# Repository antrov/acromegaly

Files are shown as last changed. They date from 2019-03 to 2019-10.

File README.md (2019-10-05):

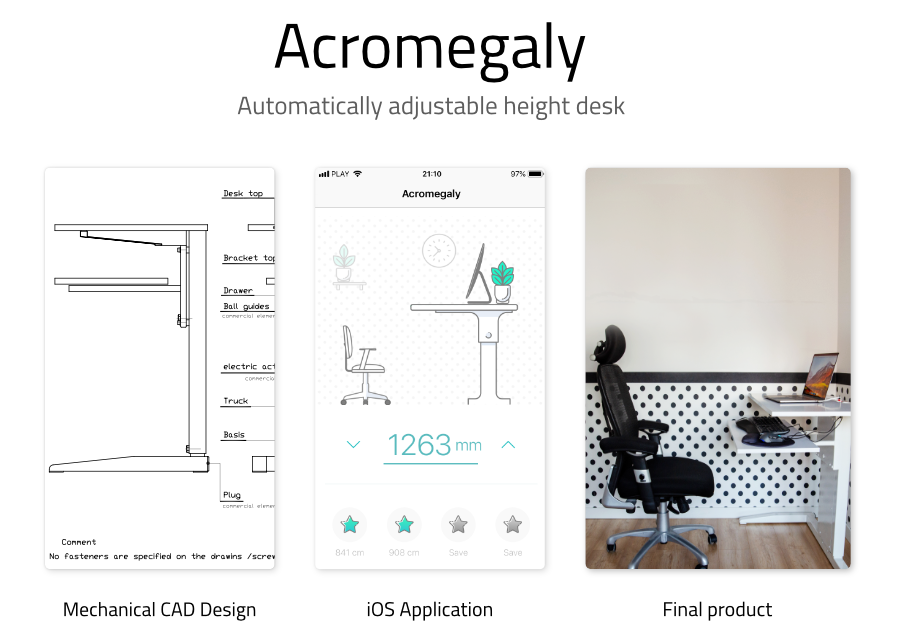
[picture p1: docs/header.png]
Header Image


Acromegaly is an open source project of the desk with automatically adjustable height. Position of the desk is controlled by Bluetooth Low Energy interface and dedicated iOS Application. 

Provided designs allows
* to build a mechanical frame of the desk, 
* to manufacture and program a controller and finally 
* to build a BLE client app. 

Total cost of components, manufacture and final polish is around 100$. 

Demo GIF

## CAD project

[GitHub repo](https://github.com/antrov/acromegaly/tree/master/CAD)
 
Full documentation of mechanical parts of the desk: frame, rails, driver mounting and desktop. Supplied in english and polish.

Designed and created by Msc Leszek Andrzejewski.

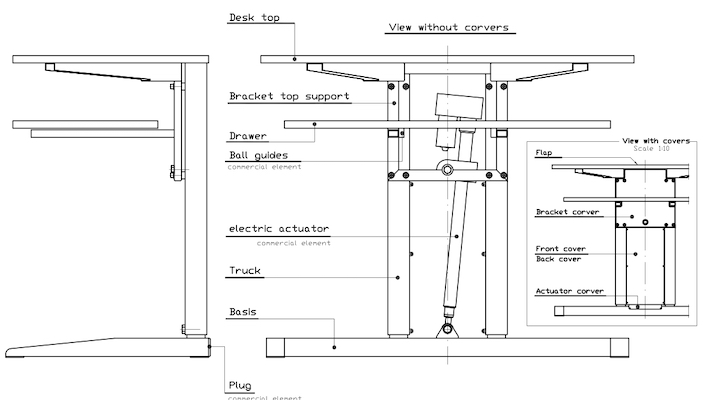
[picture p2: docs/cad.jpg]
CAD project


## PCB schematic and design

[GitHub repo](https://github.com/antrov/acromegaly/tree/master/PCB)

[Eagle](https://www.autodesk.com/products/eagle/overview) files used to design and manufacture the base PCB with a BLE controller and driver connectors. Besides, board includes an op-amp used to amplify current measurements for ADC, as well as a 8MB Flash memory. 

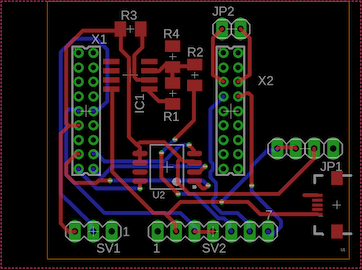
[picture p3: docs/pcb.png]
PCB Design
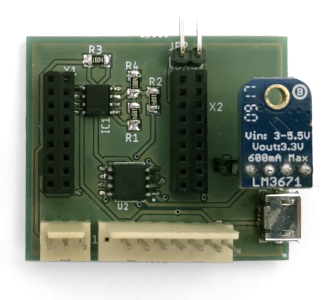
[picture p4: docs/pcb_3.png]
PCB real photo
 

## BLE controller (nRF51)

[GitHub repo](https://github.com/antrov/acromegaly-nrf51)

ANSI C code developed for the nRF51 MCU and based on its SDK. The brain of a desk controller, exposes interface for receiving commands from Bluetooth Low Energy and to broadcasts informations like: 
* current height, 
* target height, 
* movement state and direction, 
* current power 

Configured to compile with wide available and free toolchains.

## BLE client (iOS)

[GitHub repo](https://github.com/antrov/acromegaly-ios)

Swift iOS application used to present visually state of the desk and control it remotely.

* auto scanning and connecting to dedicated Acromegaly BLE device
* visual representation of current and requested desk height
* setting exact height of a desk
* swipe gesture to set bounding positions
* storing of the favourites positions

iOS Client App iOS Client App

## Contact
In case of new issues, concepts or just a will to say hello:

* antrof@gmail.com
* https://www.linkedin.com/in/handr/

## License 

Copyright 2019 Hubert Andrzejewski

This code is distributed under the terms and conditions of the MIT license.

```
Permission is hereby granted, free of charge, to any person obtaining a copy of
this software and associated documentation files (the "Software"), to deal in
the Software without restriction, including without limitation the rights to
use, copy, modify, merge, publish, distribute, sublicense, and/or sell copies of
the Software, and to permit persons to whom the Software is furnished to do so,
subject to the following conditions:

The above copyright notice and this permission notice shall be included in all
copies or substantial portions of the Software.

THE SOFTWARE IS PROVIDED "AS IS", WITHOUT WARRANTY OF ANY KIND, EXPRESS OR
IMPLIED, INCLUDING BUT NOT LIMITED TO THE WARRANTIES OF MERCHANTABILITY, FITNESS
FOR A PARTICULAR PURPOSE AND NONINFRINGEMENT. IN NO EVENT SHALL THE AUTHORS OR
COPYRIGHT HOLDERS BE LIABLE FOR ANY CLAIM, DAMAGES OR OTHER LIABILITY, WHETHER
IN AN ACTION OF CONTRACT, TORT OR OTHERWISE, ARISING FROM, OUT OF OR IN
CONNECTION WITH THE SOFTWARE OR THE USE OR OTHER DEALINGS IN THE SOFTWARE.
```

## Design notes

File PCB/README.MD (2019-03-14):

# Acromegaly PCB

[Eagle](https://www.autodesk.com/products/eagle/overview) files used to design and manufacture the base PCB with a BLE controller and driver connectors. Besides, board includes an op-amp used to amplify current measurements for ADC, as well as a 8MB Flash memory. 

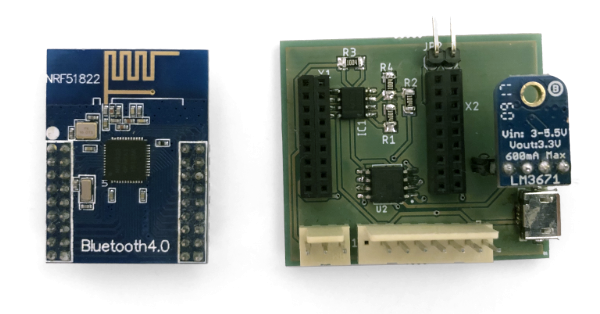
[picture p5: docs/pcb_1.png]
PCB


## Required parts:
* 2mm raster 4x9 connectors
* 2.74mm raster goldpin connectors
* M45PE80 - 8MB FLASH Memory
* LM358 - op-amp for current measurement
* double BTS 7960 as H-Bridge driver - [sample](http://www.alselectro.com/motor-driver-hbridge-43amps-bts7960.html)
* LM3671 3.3V Buck Converter Breakout - 3.3V - step-down power supply from 5V to 3.3V - [sample](https://www.adafruit.com/product/2745)
* nRF51 Core Board - 2mm raster pins - [sample](https://www.waveshare.com/core51822.htm)
* 4x 1MΩ -  SMD 1206 Resitors
* LM393 with slot detector - [sample](https://www.electrokit.com/produkt/modul-med-optisk-lasgaffel/)
* Mask for slot detector - [PDF](https://github.com/antrov/acromegaly/tree/master/PCB/gap_mask.pdf)

## Flashing

During development on DK board, flashing is done by integrated JLink (SEGGER) programmer. In order to flash Acromegaly PCB it is necessary to connect DK VVC/GND instead of LM3671 and SWDIO/SWCLK to dedicated PCB connectors accoriding to [following rules](https://electronut.in/nrf51-dk-external-programming/)

## Slot detector

[Mask PDF](https://github.com/antrov/acromegaly/tree/master/PCB/gap_mask.pdf)

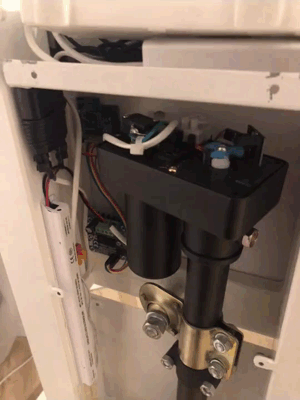
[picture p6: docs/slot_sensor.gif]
Slot senor in action


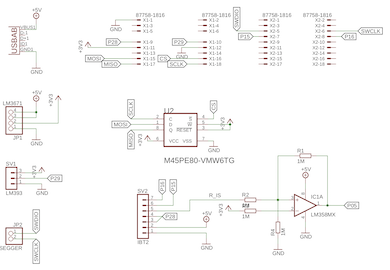
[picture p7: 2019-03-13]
docs/schematic.png

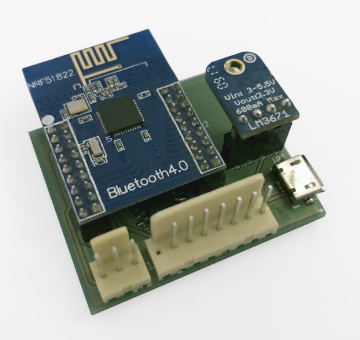
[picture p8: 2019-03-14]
docs/pcb_2.png

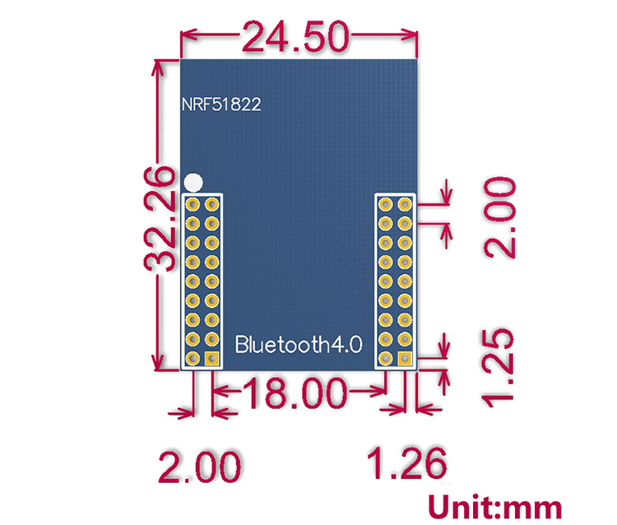
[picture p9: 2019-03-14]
PCB/Datasheets/Core51822-size.jpg

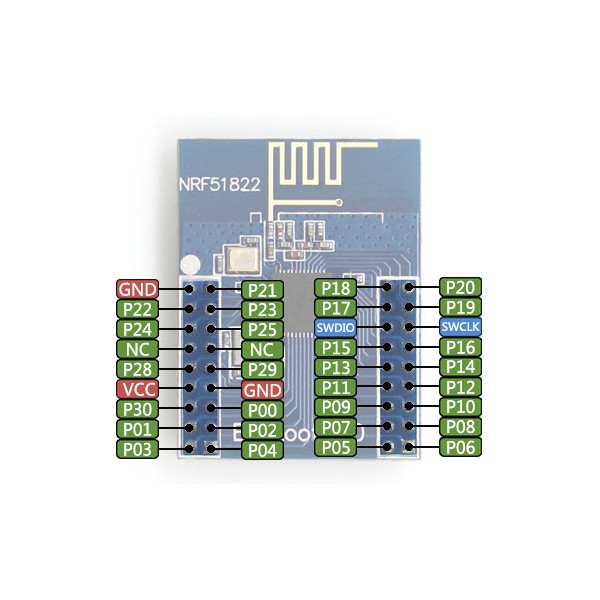
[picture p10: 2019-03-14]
PCB/Datasheets/core51822-board.jpg

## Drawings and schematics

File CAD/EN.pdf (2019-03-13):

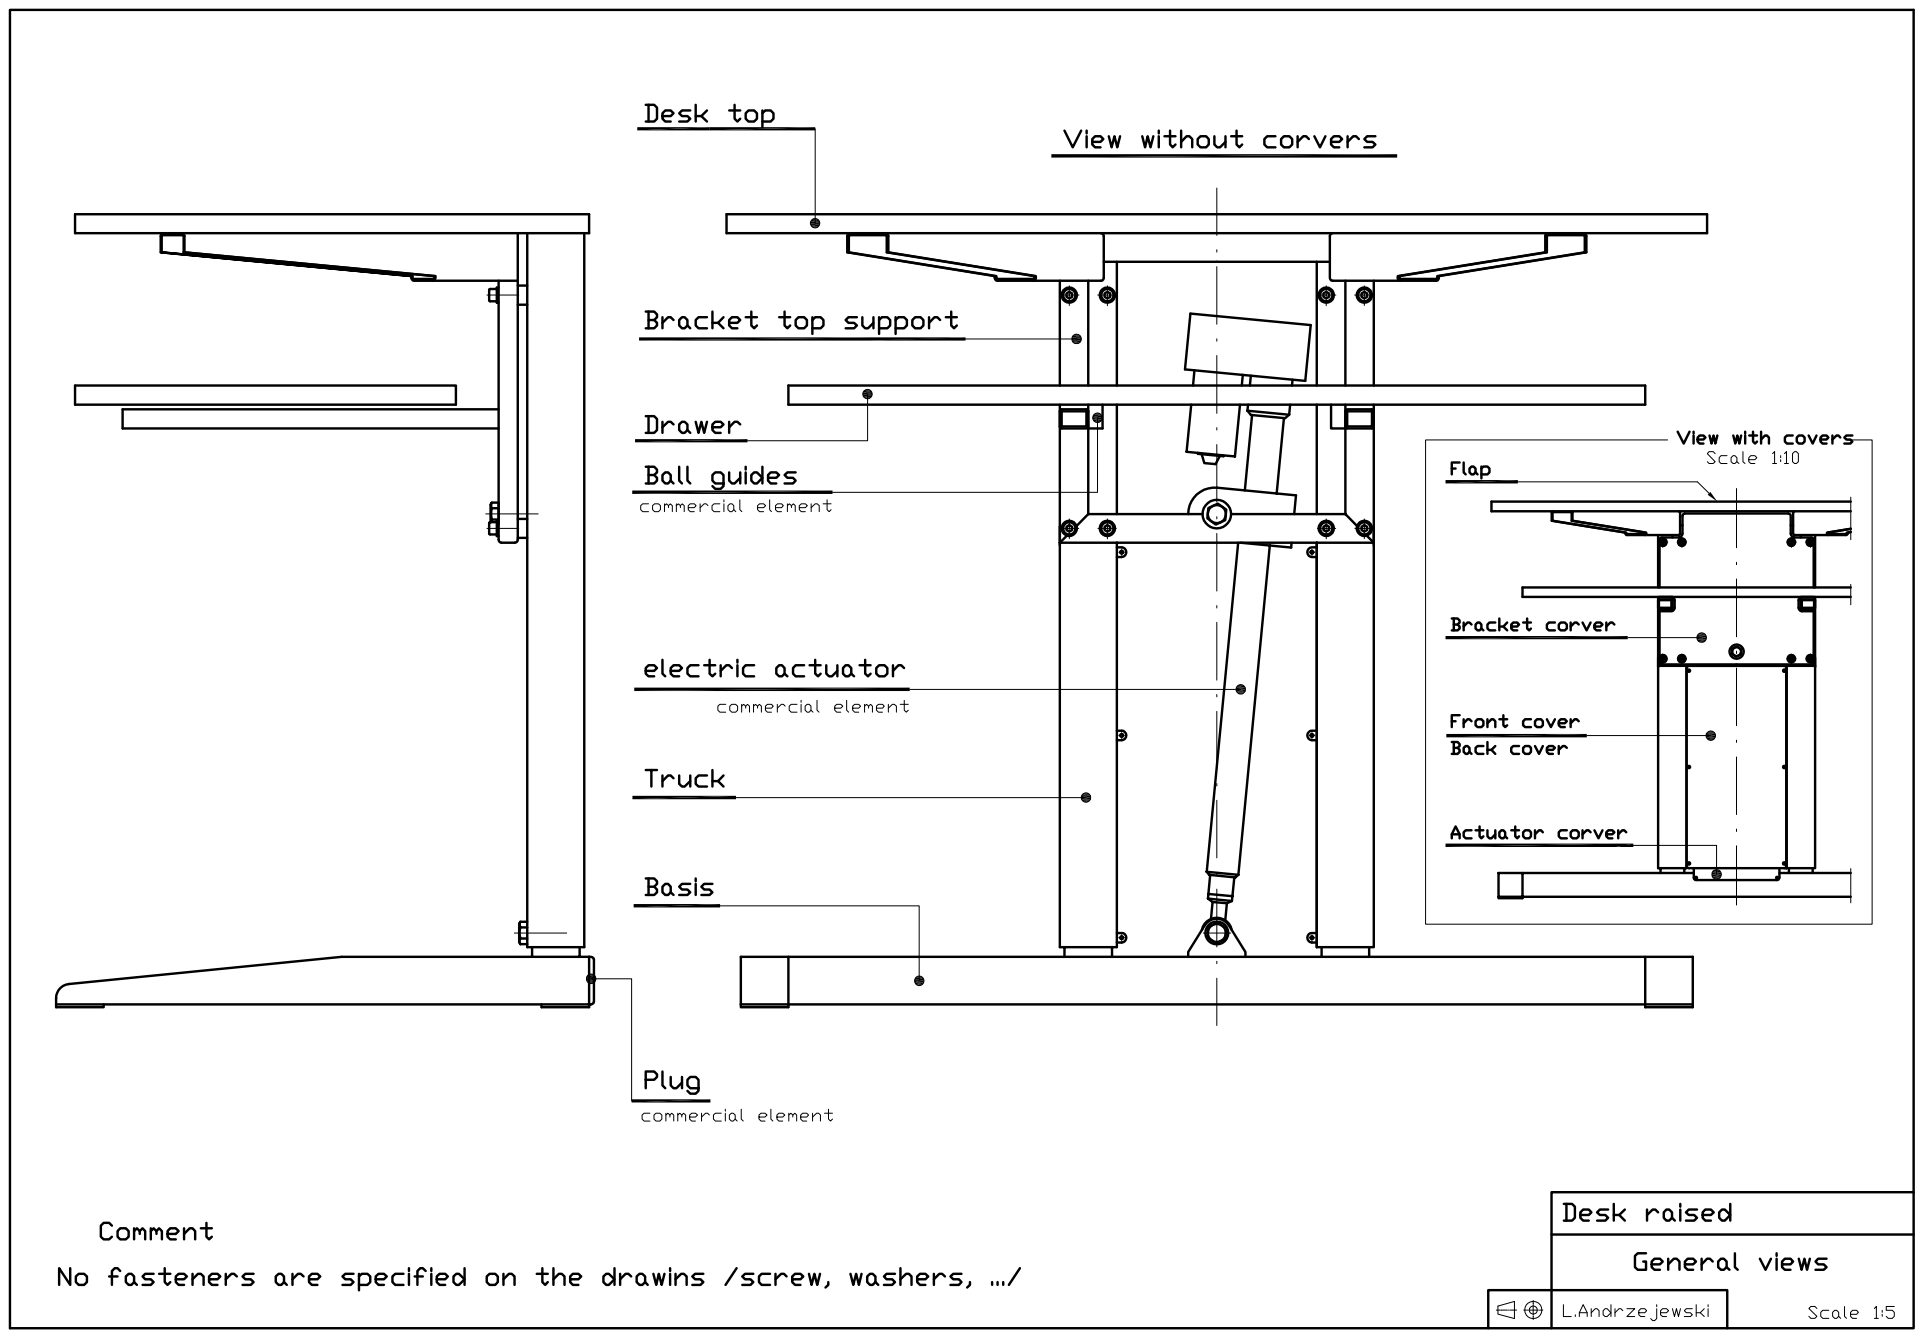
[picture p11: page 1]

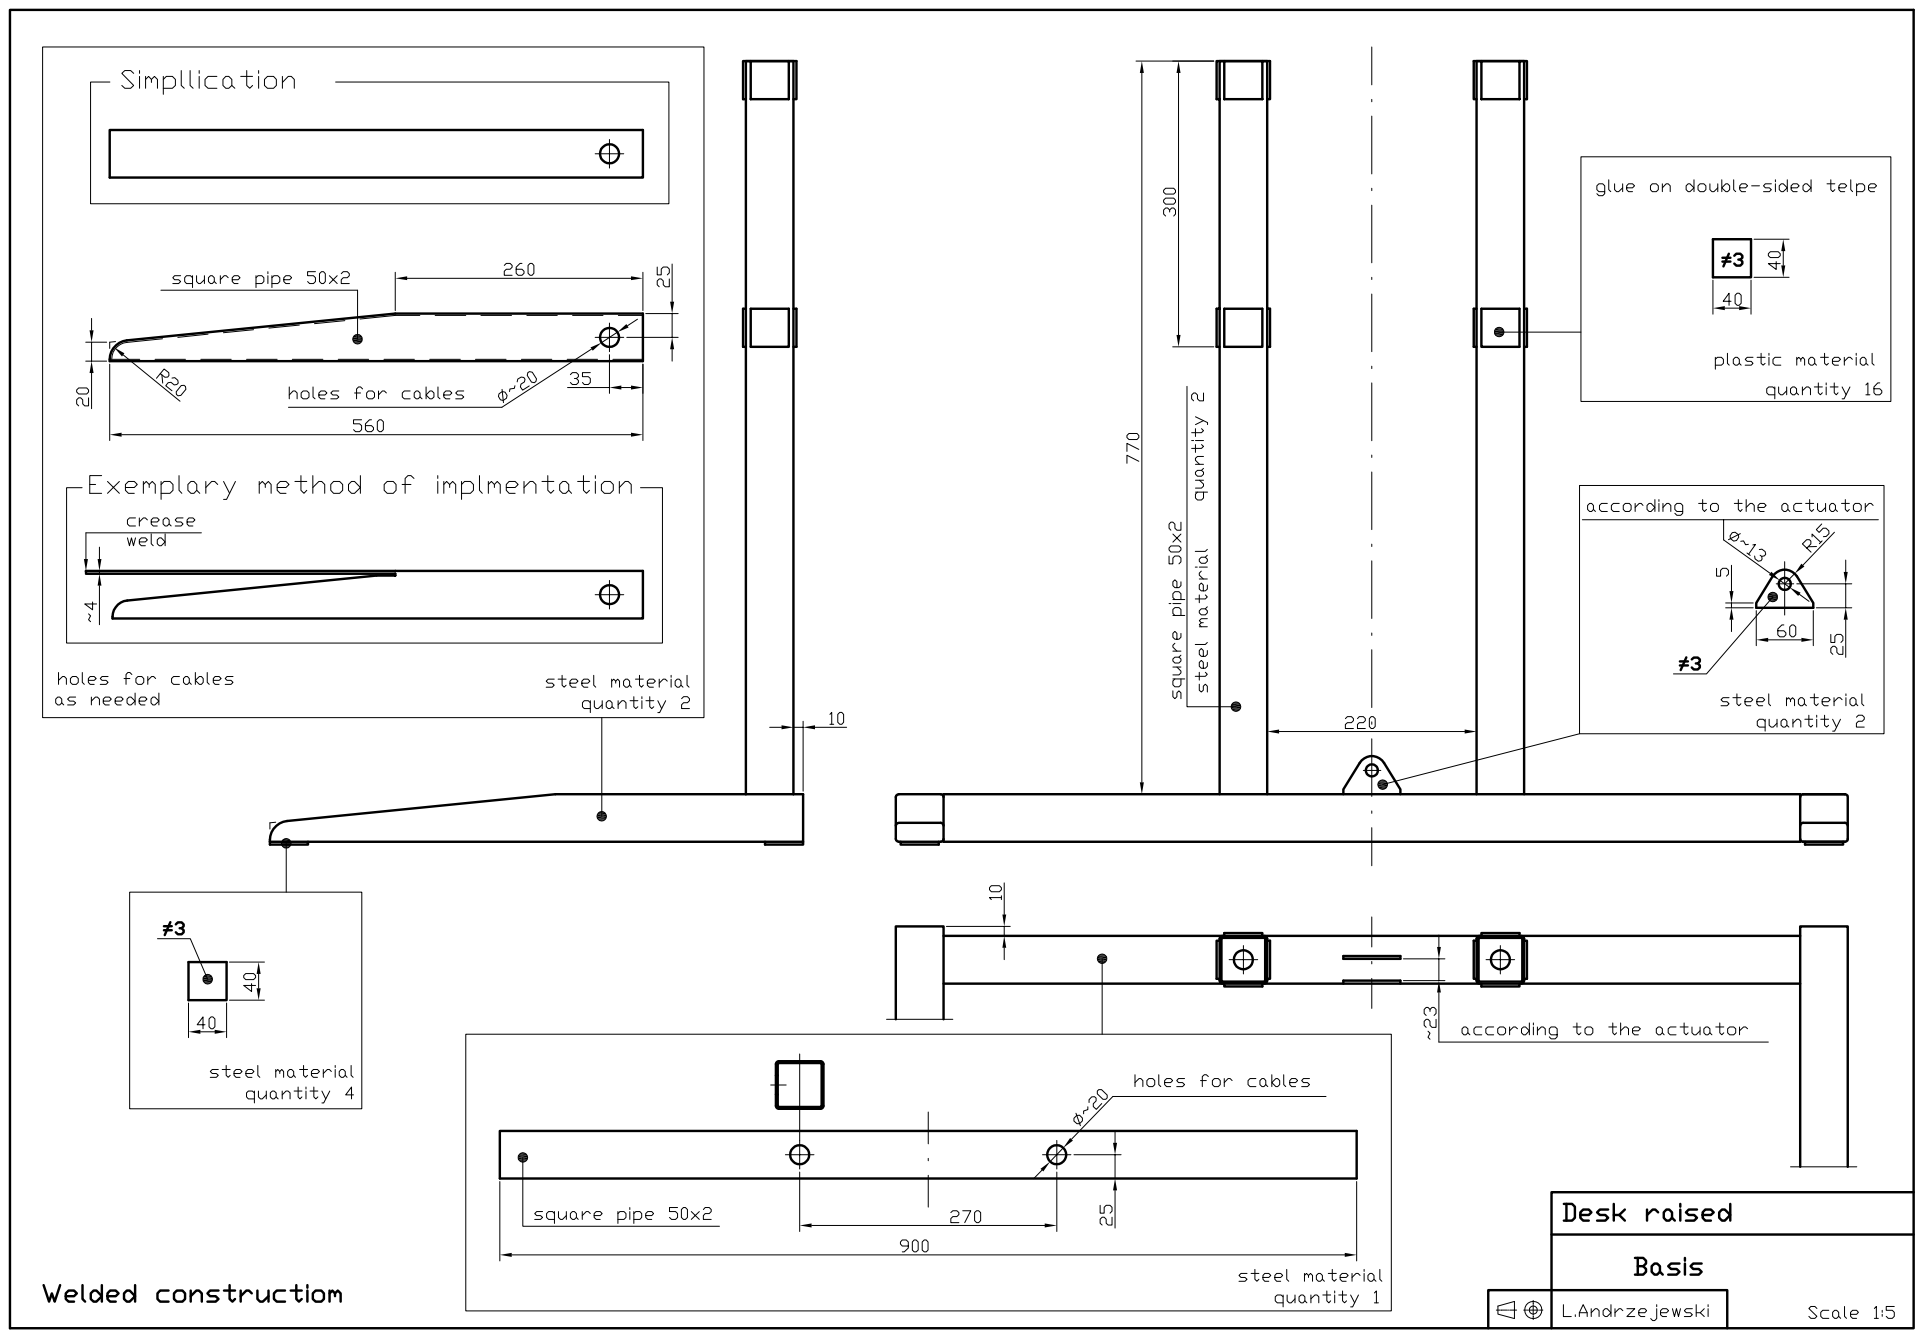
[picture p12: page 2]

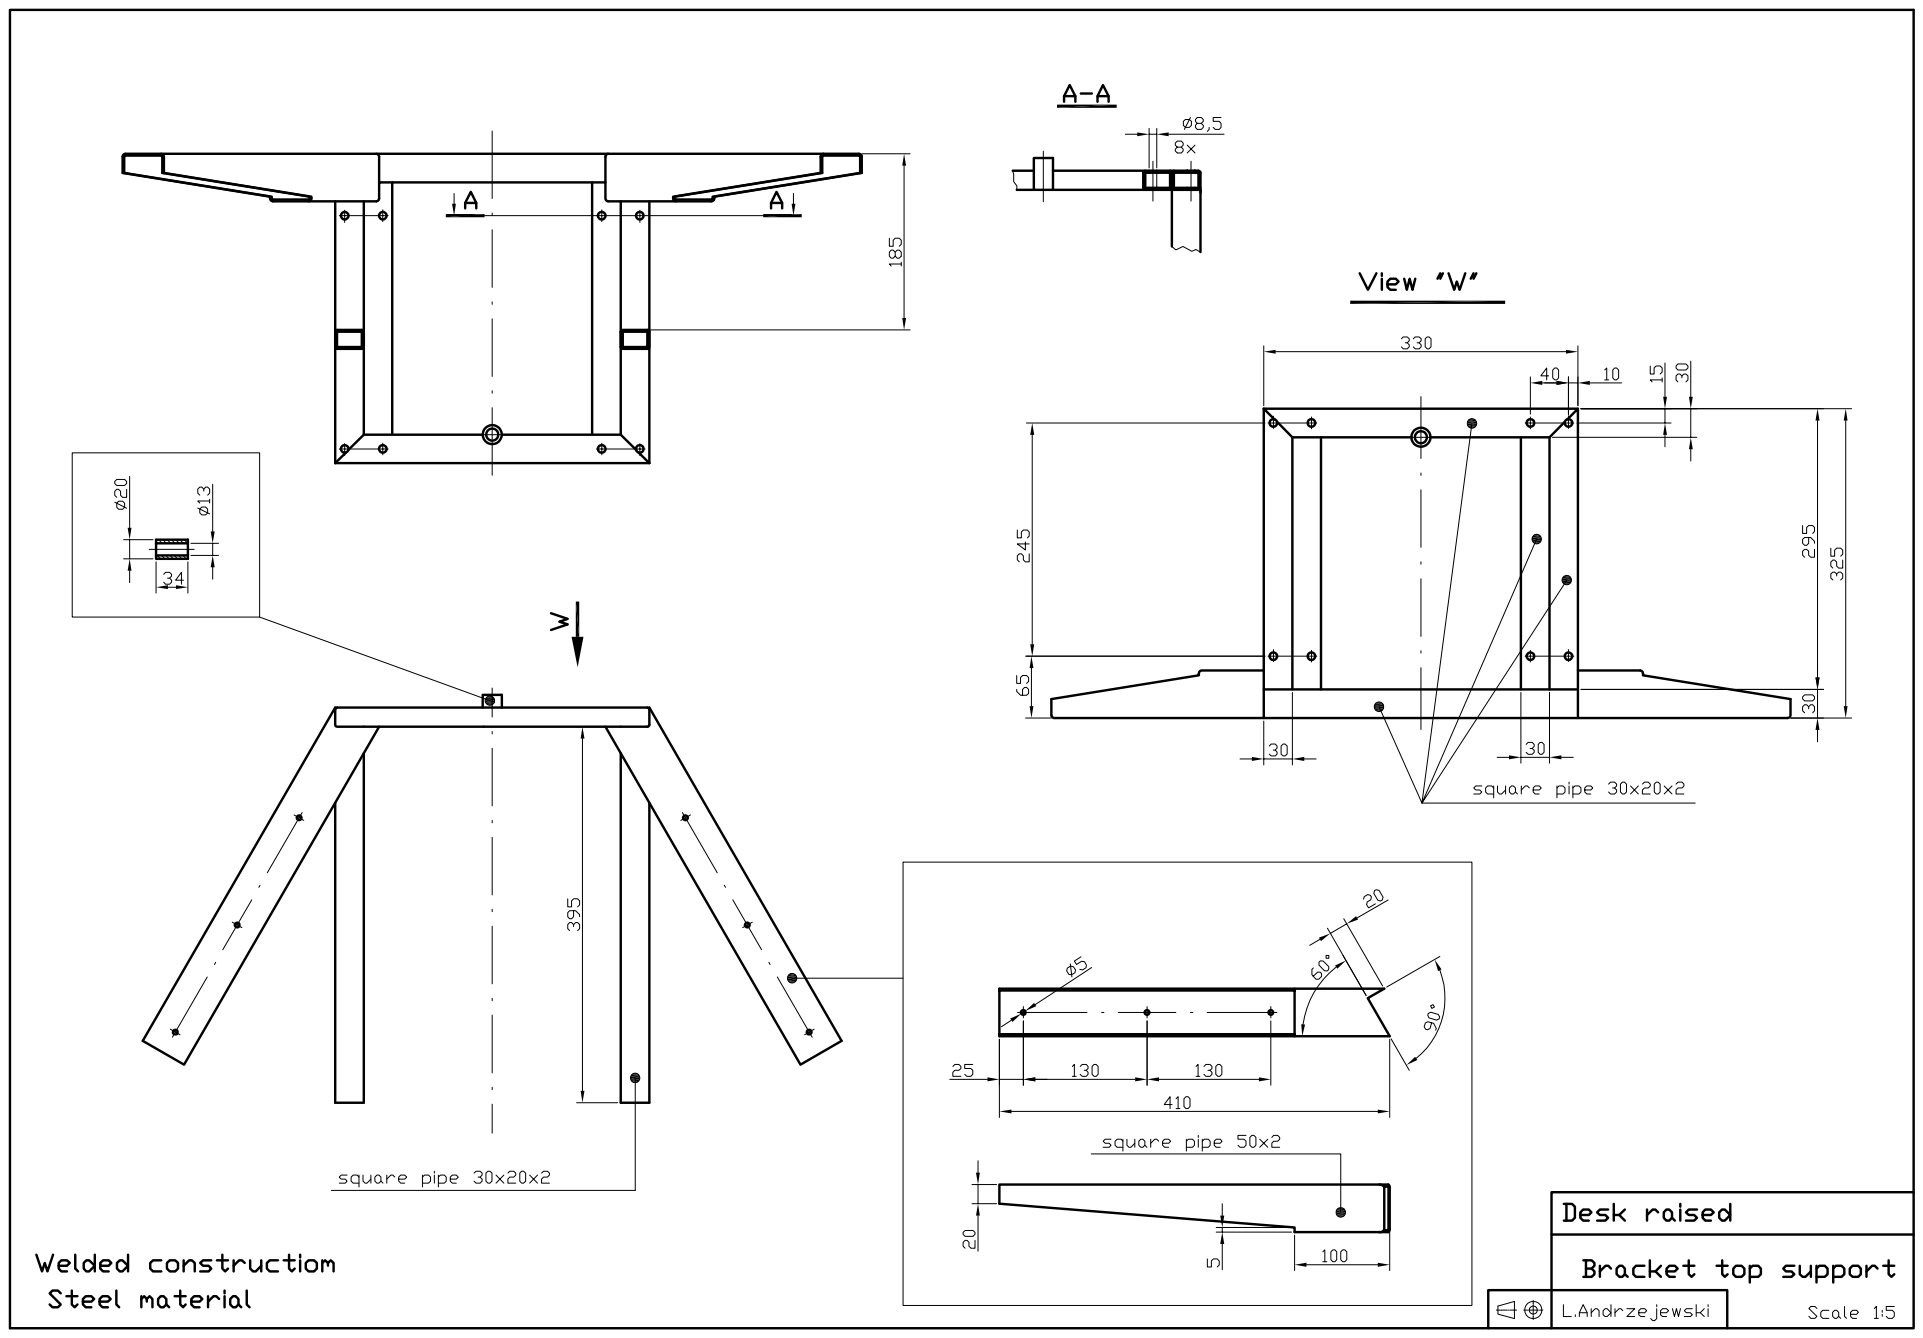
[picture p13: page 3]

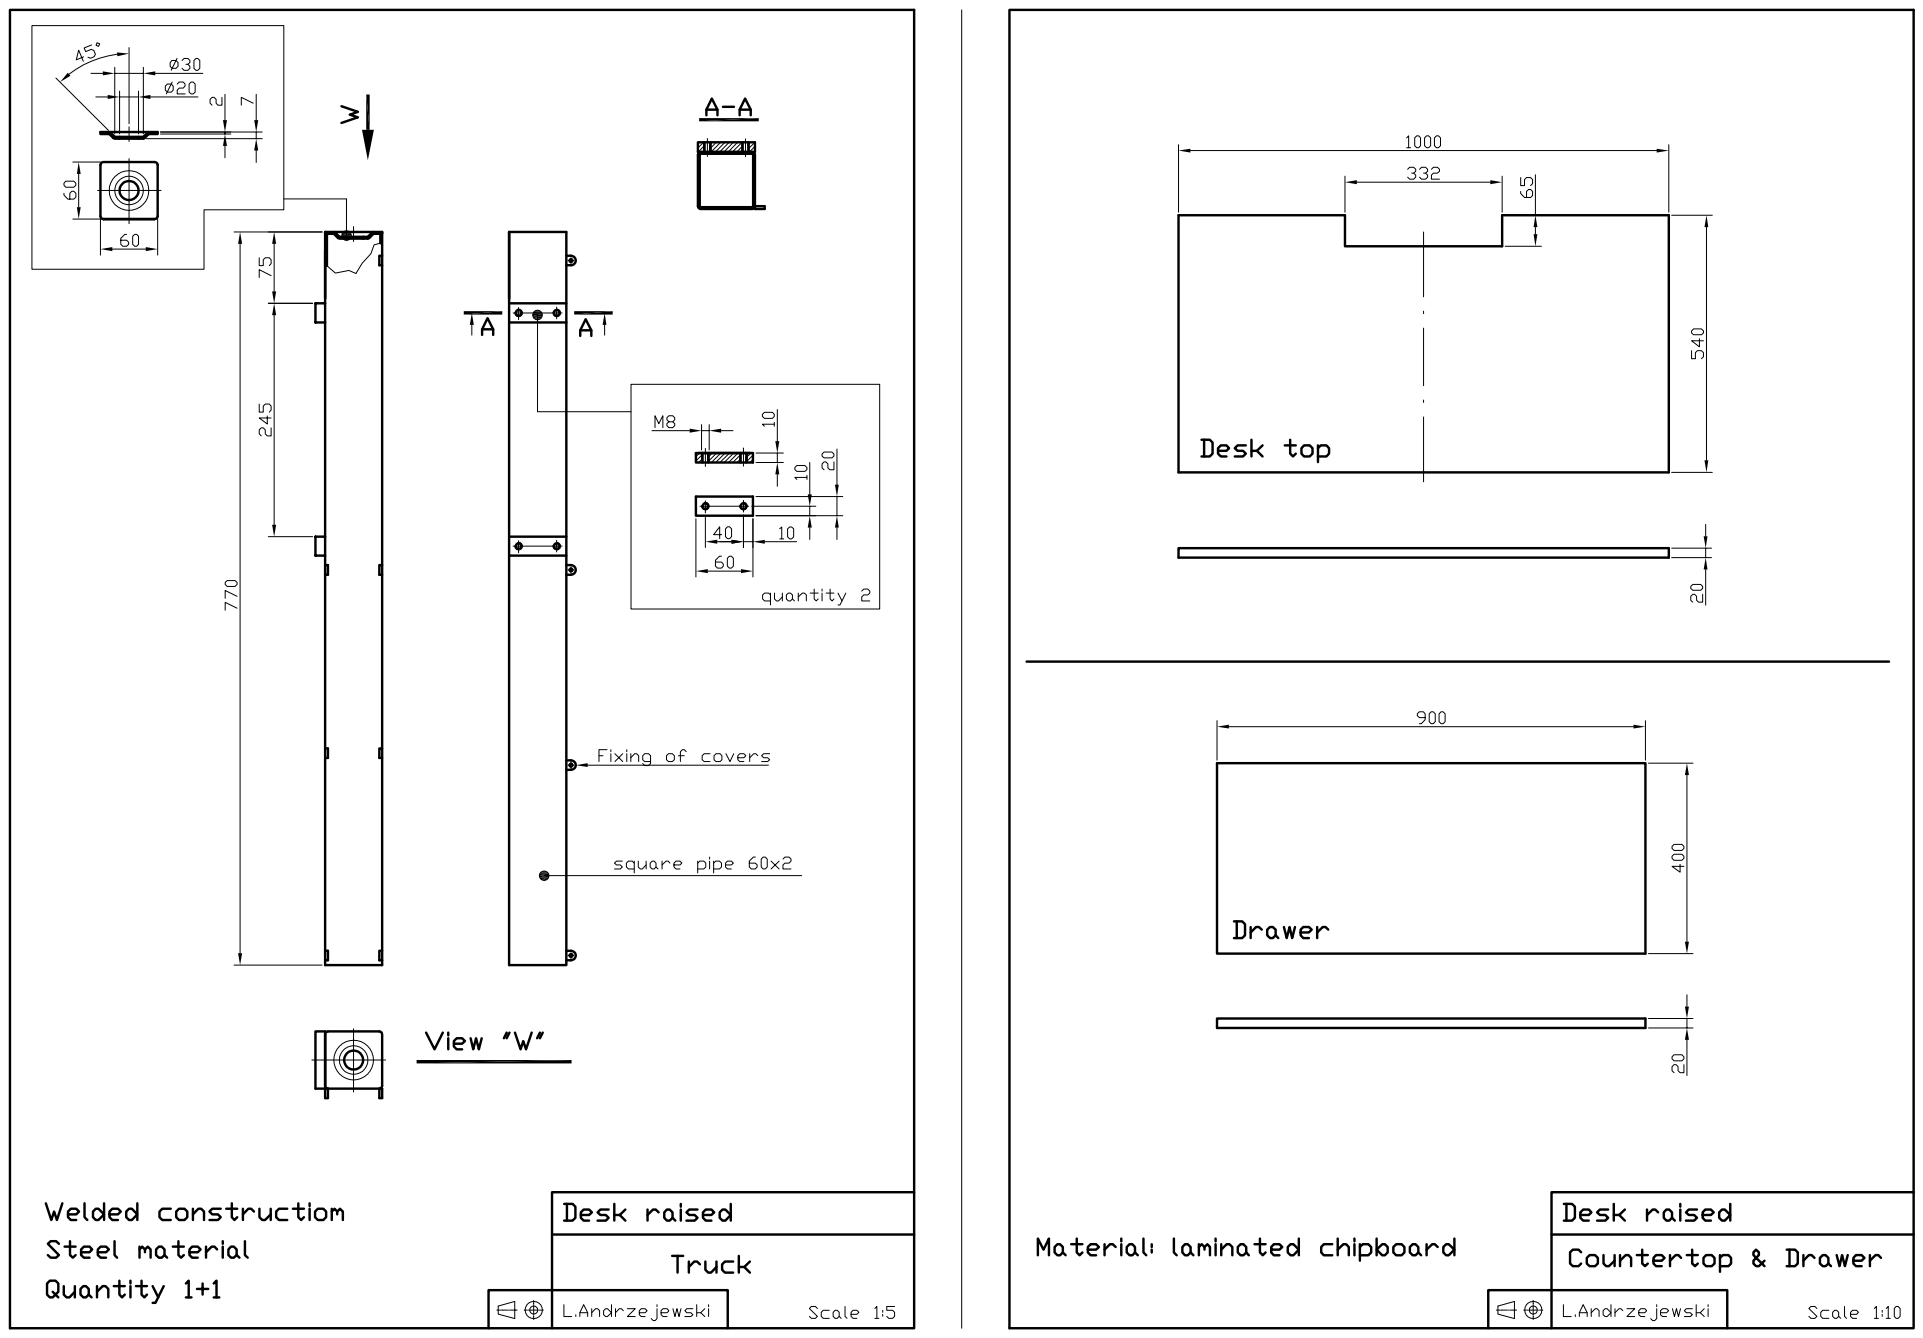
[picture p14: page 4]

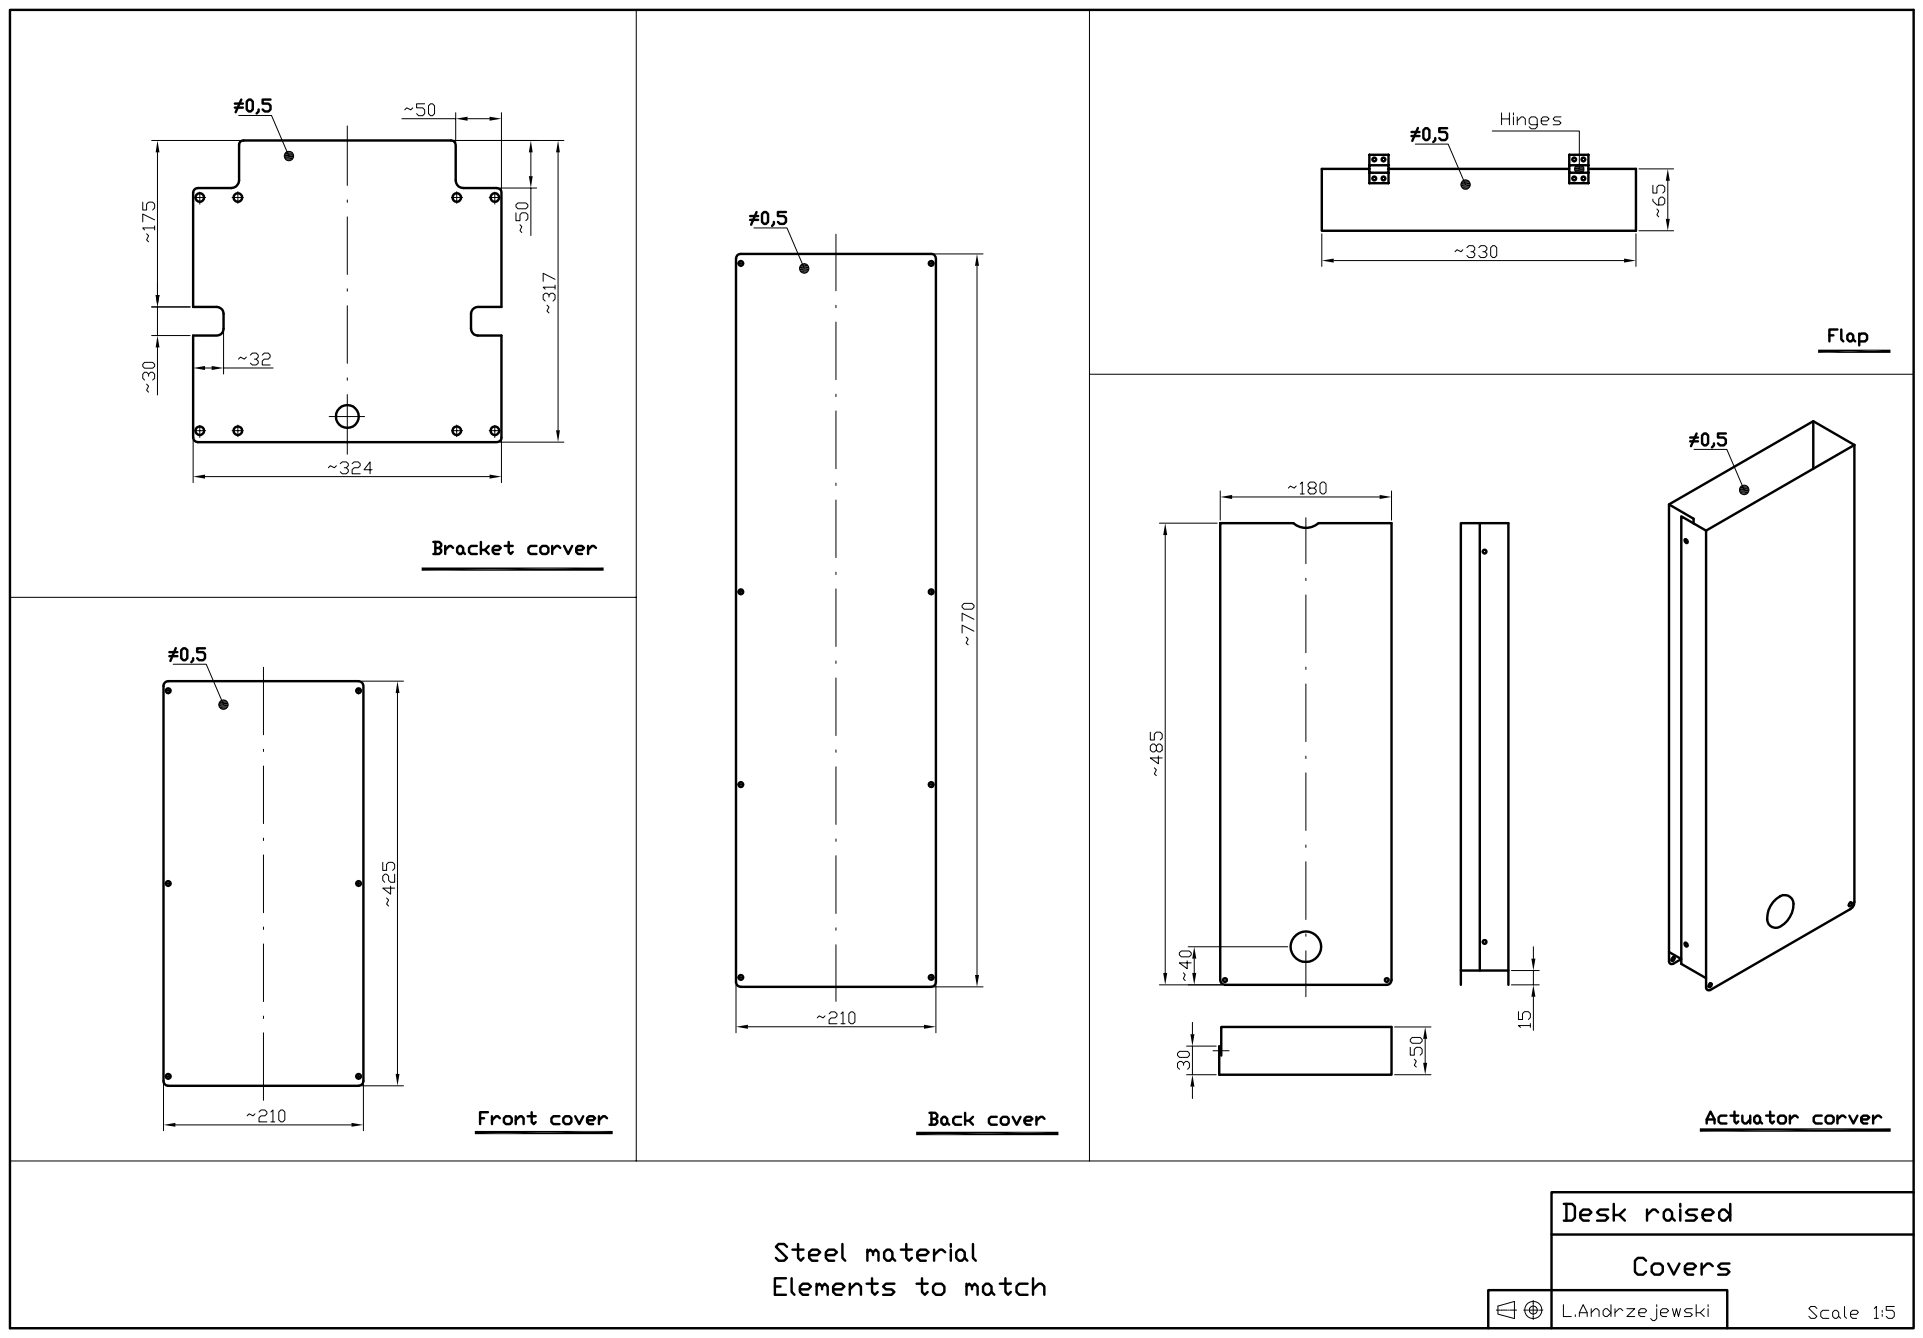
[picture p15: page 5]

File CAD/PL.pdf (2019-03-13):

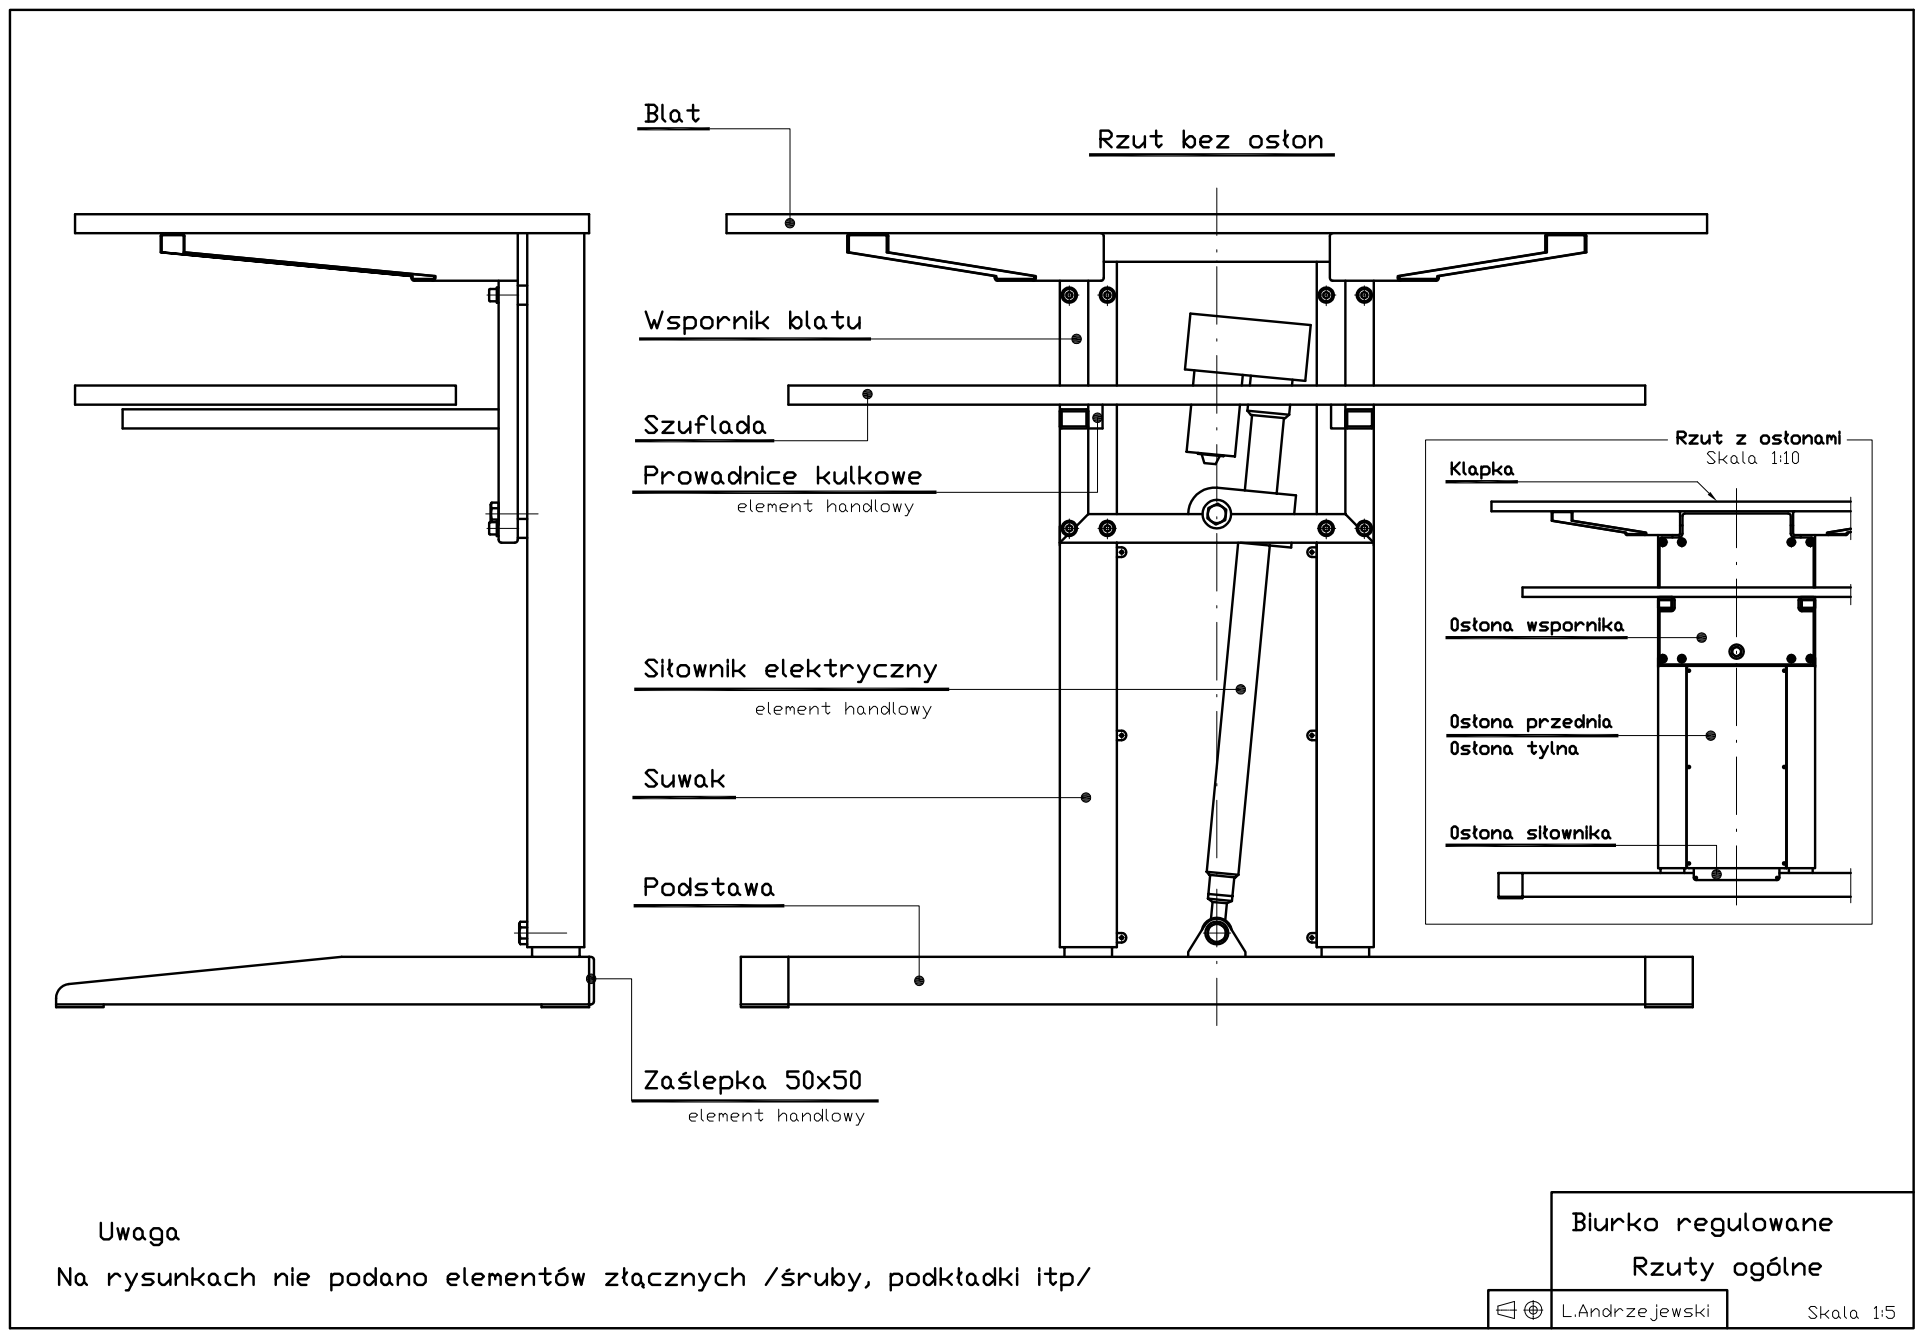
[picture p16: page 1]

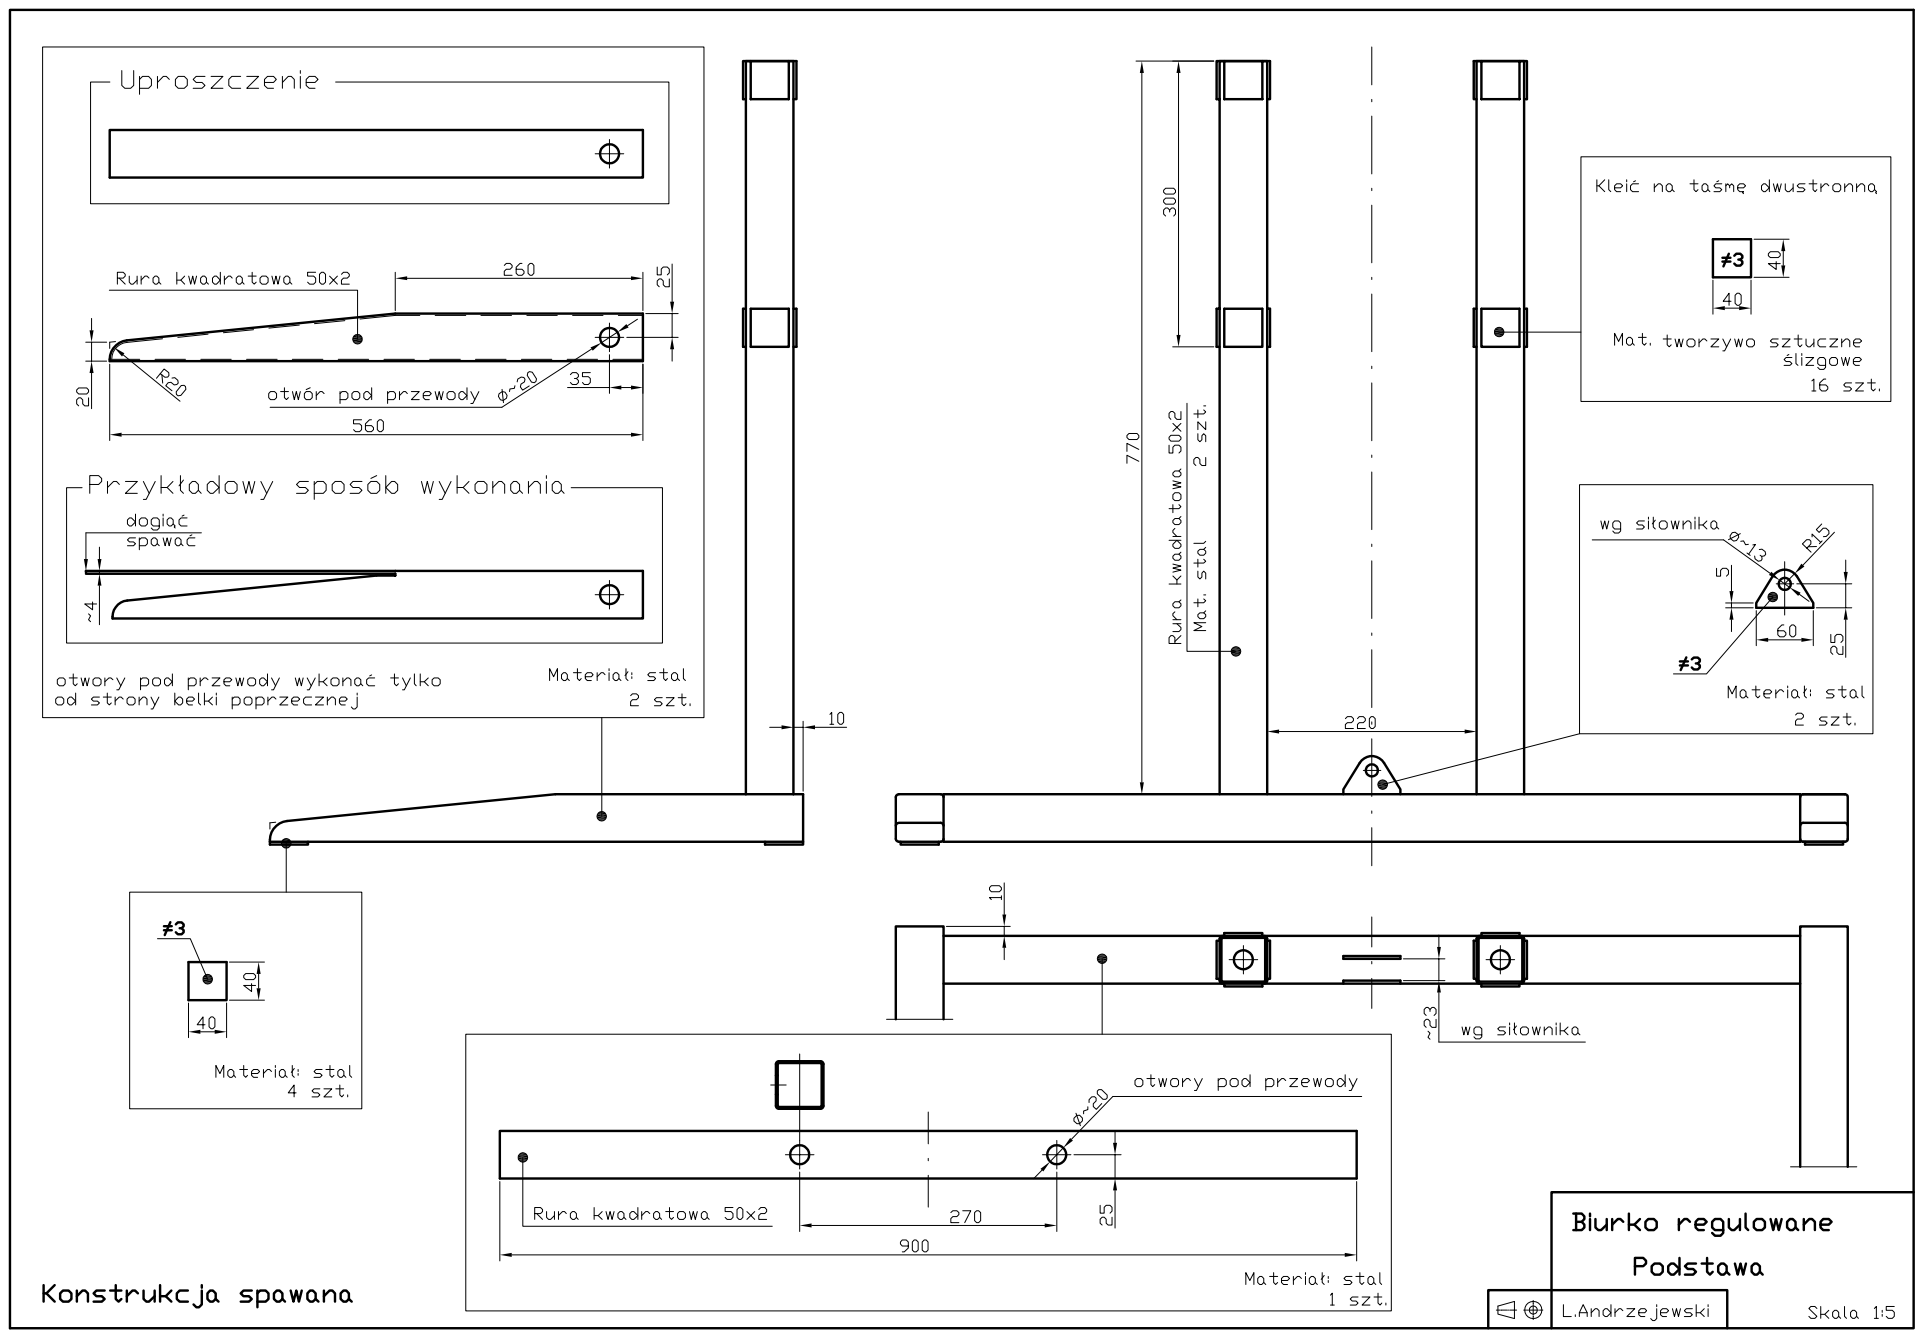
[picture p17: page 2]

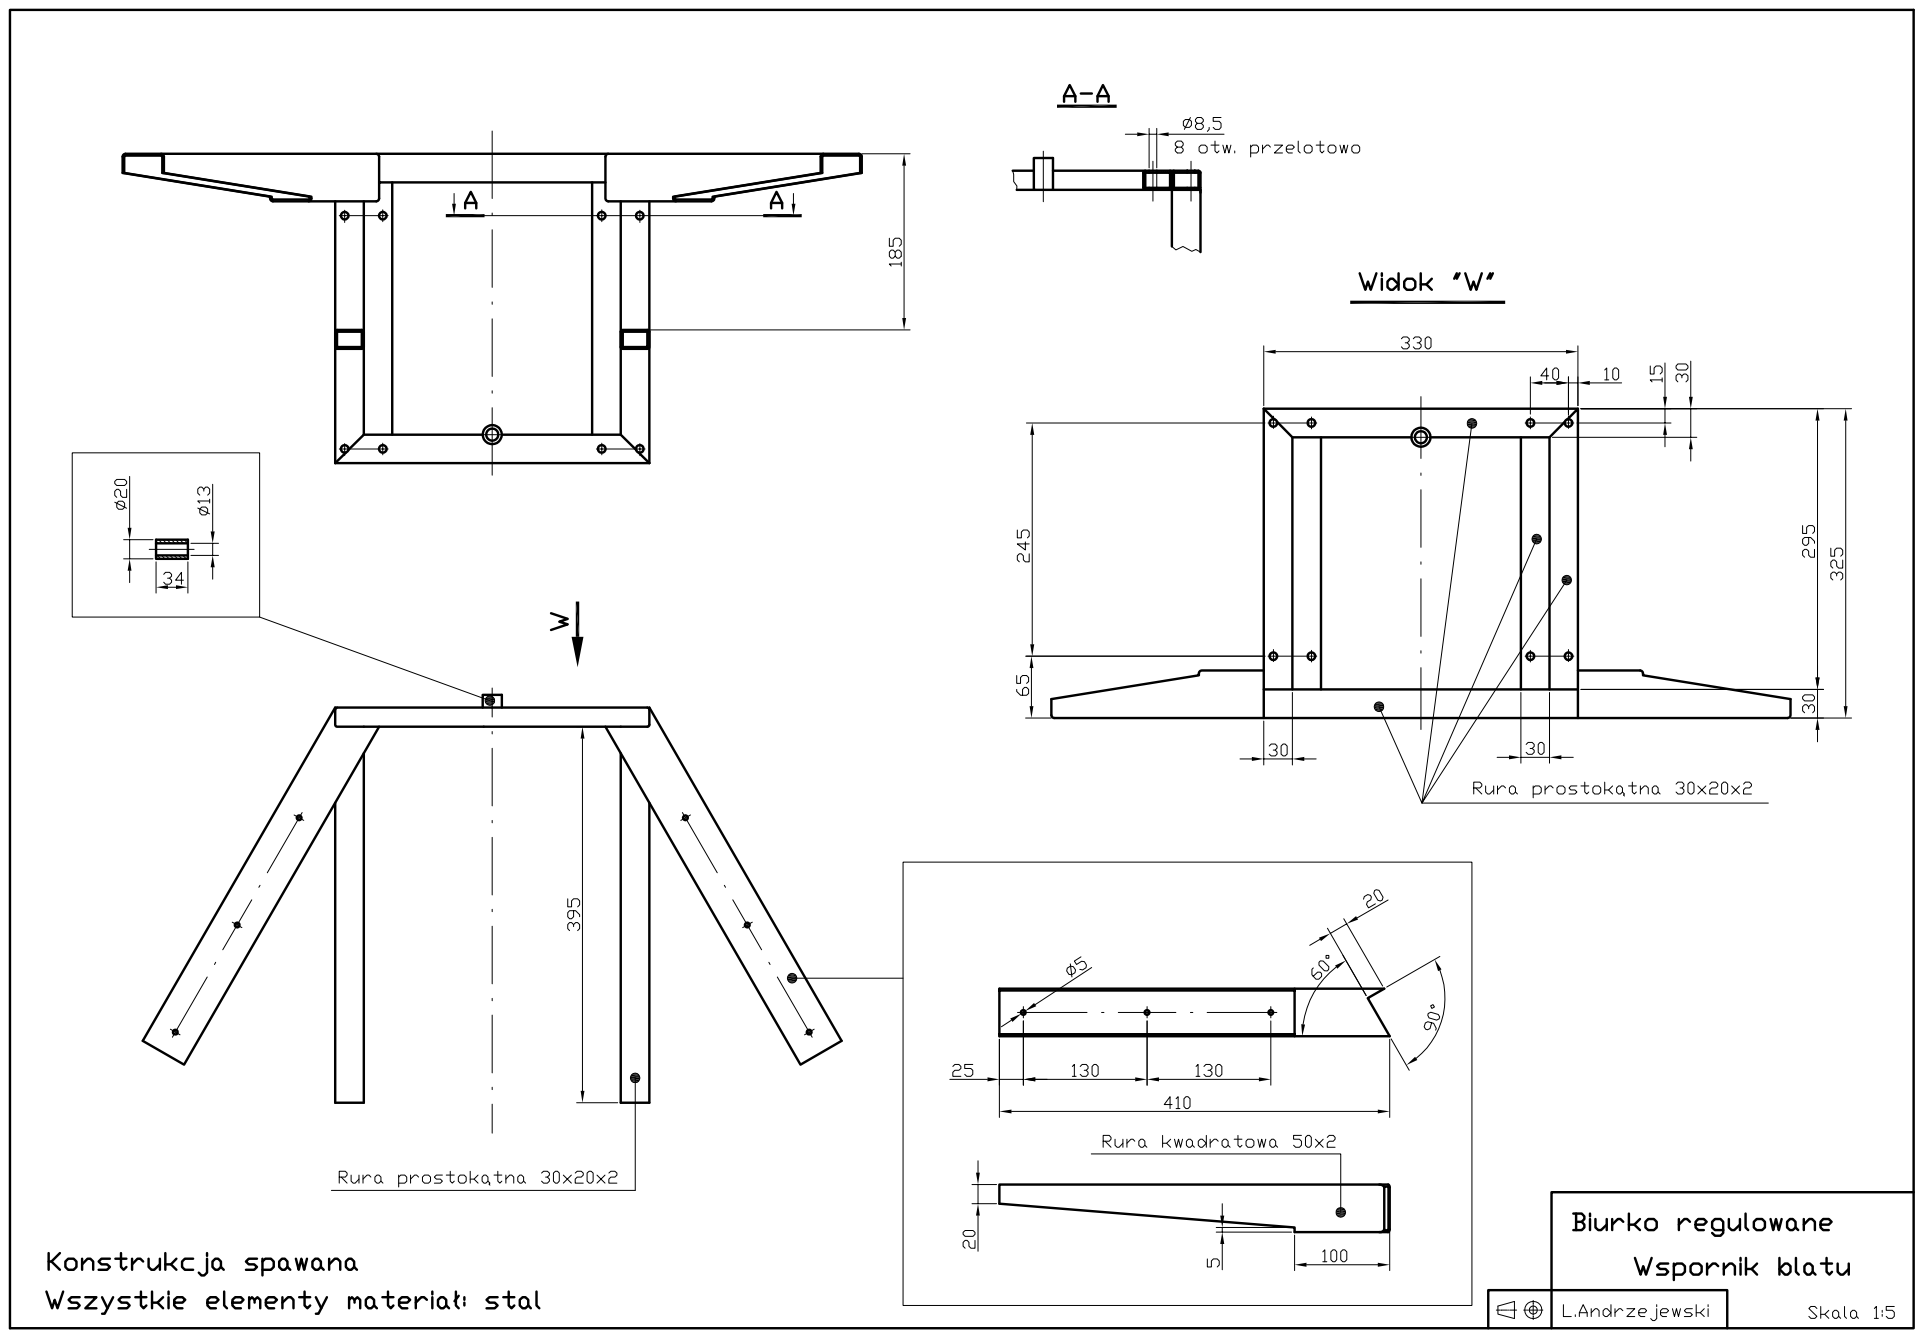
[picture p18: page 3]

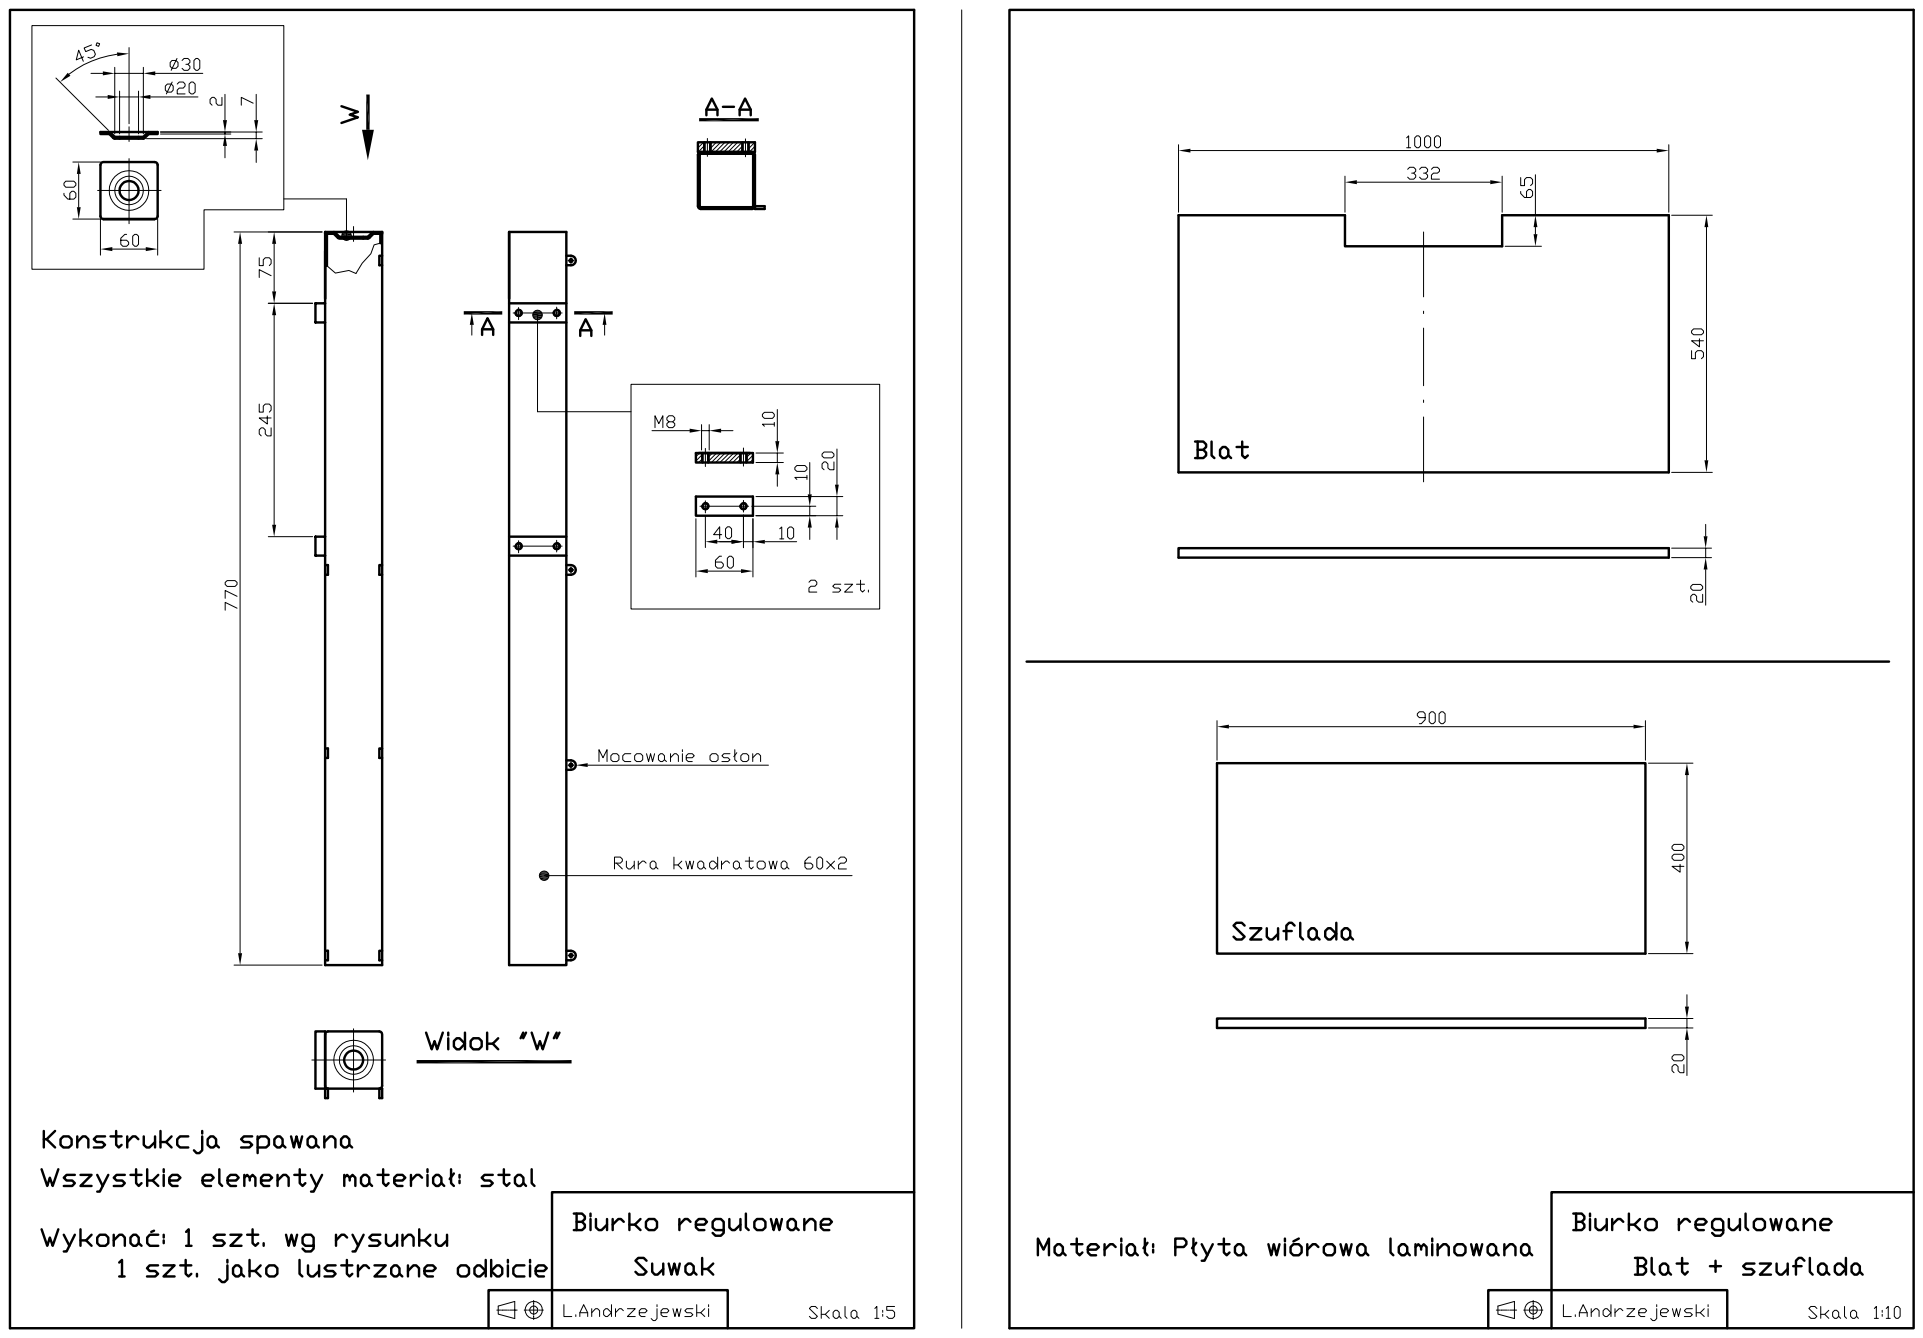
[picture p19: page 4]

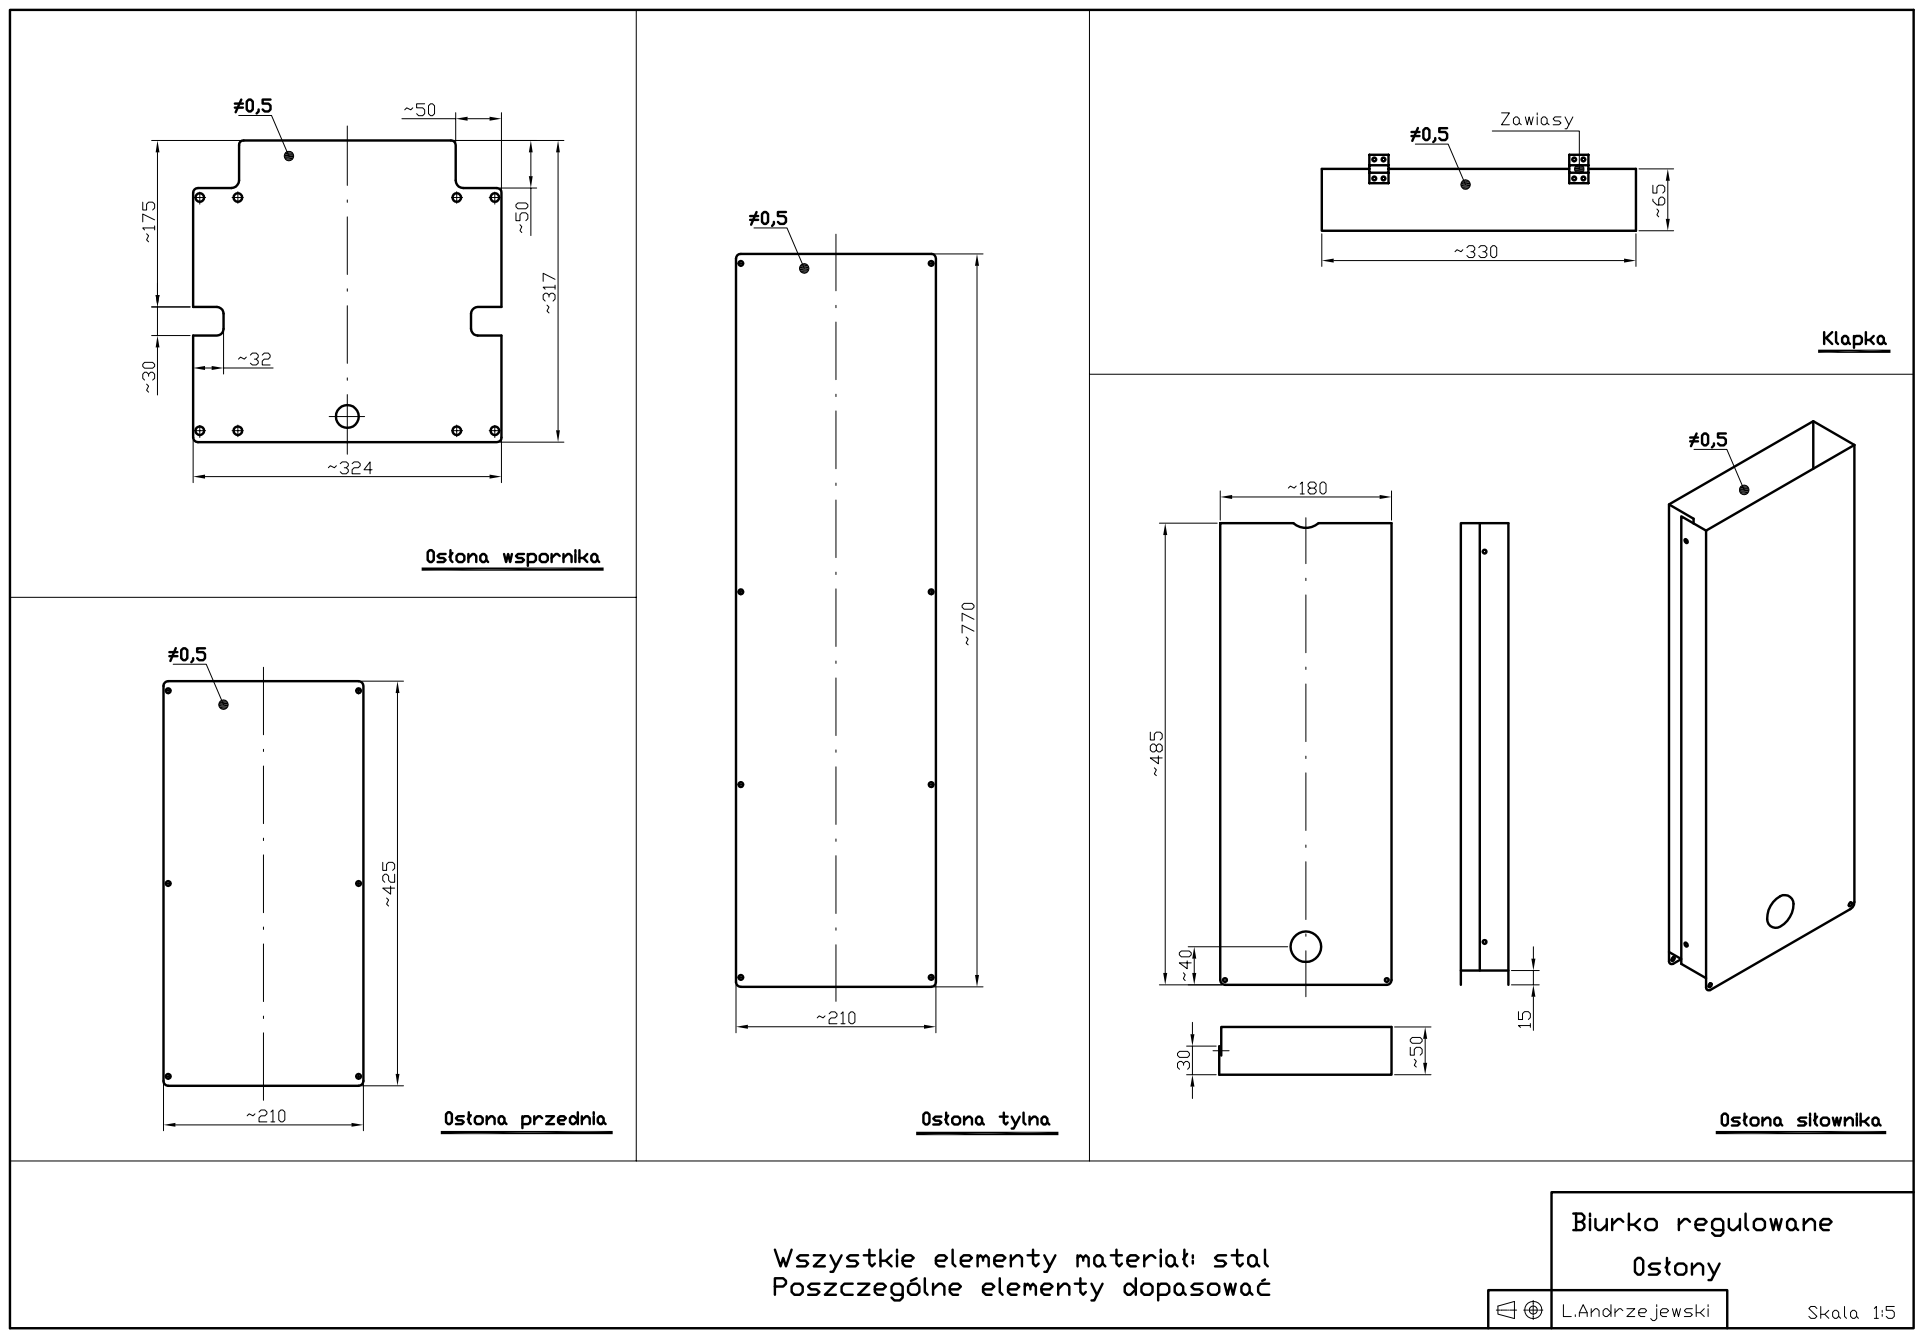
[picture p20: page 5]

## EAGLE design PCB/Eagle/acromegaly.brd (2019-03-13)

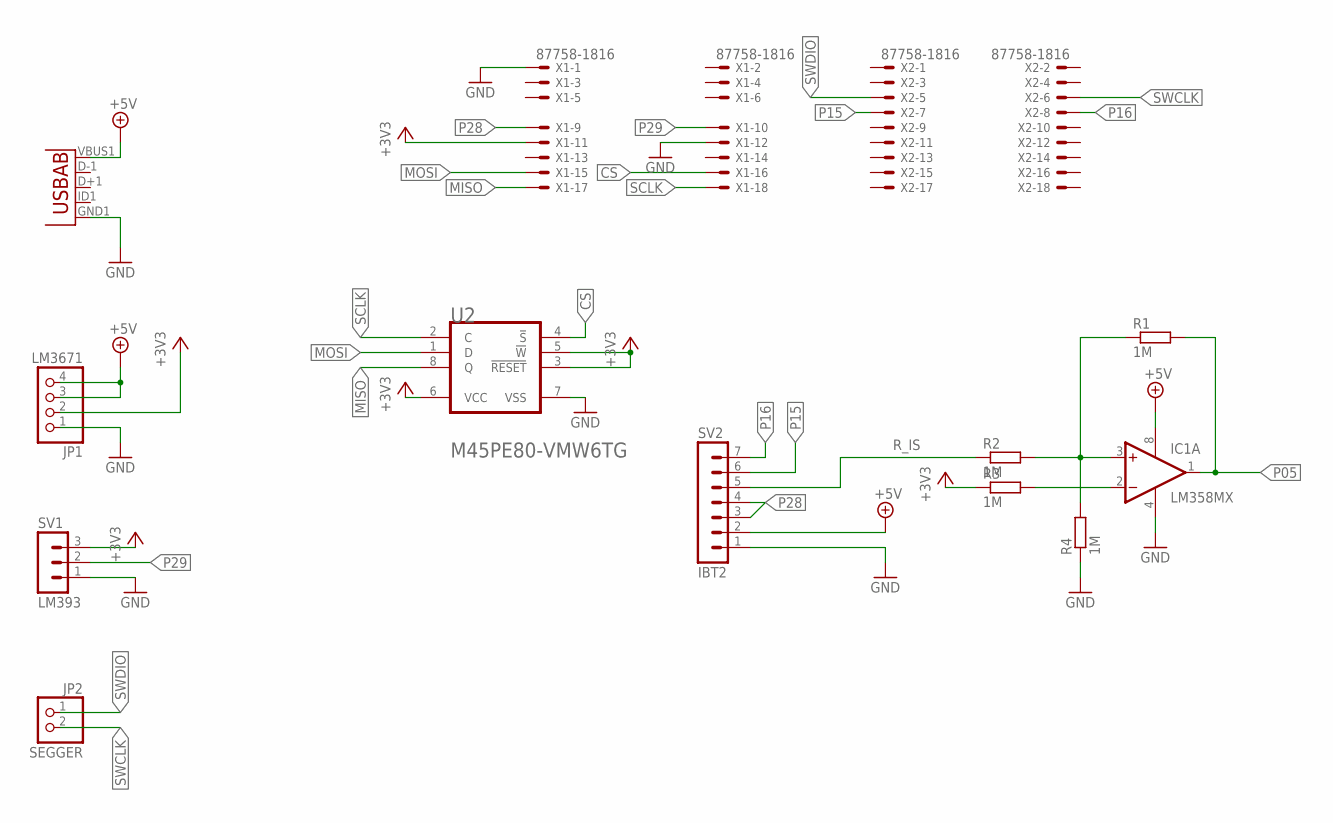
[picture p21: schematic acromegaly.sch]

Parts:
IC1: LM358MX; SO08
JP1: LM3671; 1X04
JP2: SEGGER; 1X02
R1, R2, R3, R4: 1M; M1206
SV1: LM393; MA03-1
SV2: IBT2; MA07-1
U1: USB""; USB-MICRO-SMD
U2: MICRON_M45PE80-VMW6TGMICRON_M45PE80-VMW6TG_0_0; MICRON_M45PE80-VMW6TG_0
X1, X2: 87758-1816

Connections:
+3V3: JP1.2, R3.1, SV1.3, U2.3 (!RESET!), U2.5 (!W!), U2.6 (VCC), X1.11
+5V: IC1.8 (V+), JP1.3, JP1.4, SV2.2, U1.VBUS1 (VBUS)
CS: U2.4 (!S!), X1.16
GND: IC1.4 (V-), JP1.1, R4.1, SV1.1, SV2.1, U1.GND1 (GND), U2.7 (VSS), X1.1, X1.12
MISO: U2.8 (Q), X1.17
MOSI: U2.1 (D), X1.15
unnamed: IC1.3 (+IN), R1.1, R2.2, R4.2
unnamed: IC1.2 (-IN), R3.2
P05: IC1.1 (OUT), R1.2
P15: SV2.6, X2.7
P16: SV2.7, X2.8
P28: SV2.3, SV2.4, X1.9
P29: SV1.2, X1.10
R_IS: R2.1, SV2.5
SCLK: U2.2 (C), X1.18
SWCLK: JP2.2, X2.6
SWDIO: JP2.1, X2.5

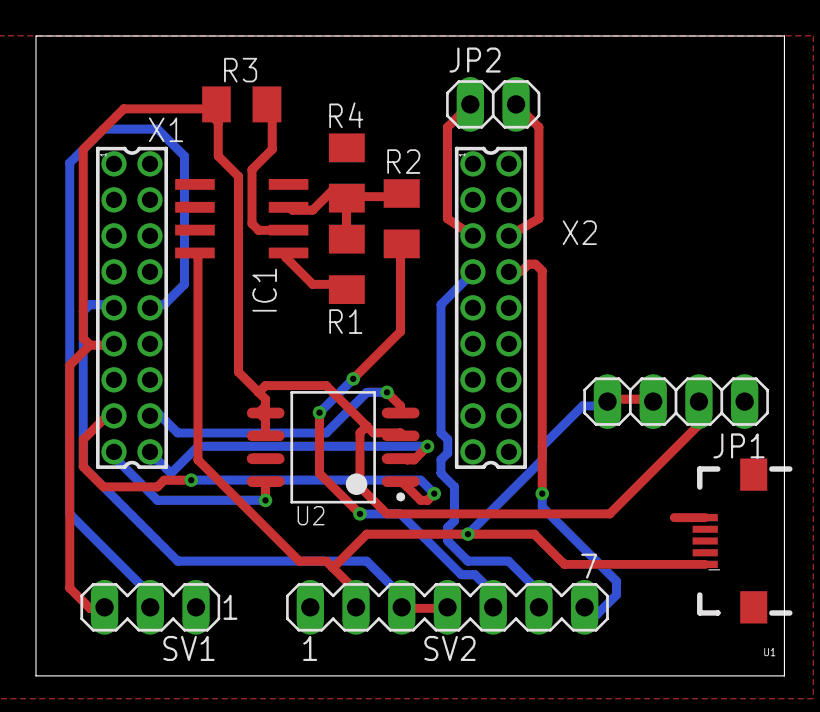
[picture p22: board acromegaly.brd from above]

Board: 2 copper layers, 41.6 x 35.5 mm, 13 parts (0 on the bottom side), 17 nets.

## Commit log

2019-03-13 PCB and schematic for docs
2019-03-13 PCB resizsed
2019-03-13 CAD preview for docs
2019-03-13 Eagle files
    [acromegaly.brd, acromegaly.sch]
2019-03-13 CAD designs as PDF files
2019-03-14 README updated
    [acromegaly.brd, acromegaly.sch]
2019-03-14 PCB docs
    [acromegaly.brd, acromegaly.sch]
2019-03-14 PCB photos
2019-03-14 PCB photo updated
2019-03-14 Slot sensors GIF
